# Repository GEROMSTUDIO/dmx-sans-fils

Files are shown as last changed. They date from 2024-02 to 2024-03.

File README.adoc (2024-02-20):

= DMX sans fils =

= Présentation du projet =
Le projet est de créer des boitiers DMX sans fils

= Qu'est ce que le DMX =
Le DMX est une norme dans le milieu du spectacle,
on la retrouve sur la plupart des appareils, projecteurs, machine à fumée...
 Elle permet de contrôler c'est appareil en utilisant qu'un câble.
Tout les appareils reçoivent le signal en même temps.

= Architecture =
Le projet est basée sur `Arduino`

= Fonctionnement =
Le systéme est constitué de deux boitiers, un émetteur et un récepteur.
L'émetteur lis le signal DMX envoyer par la console, l'envoie au récepteur
par onde radio (> 2.4ghz). Le récepteur écrit le signal sur le DMX.

= Composant =

* `RF-NANO`
* `MAX485`
* `WS2812D`
* `Bouton poussoir`
* `Condensateur électrolytique 16v 100µF`
* `Interupteur à glisiére`
* `Connecteur DMX (XLR)`

== License ==

 Ce travail est sous licence CC BY-NC-SA 4.0© 2024 <geromstudio@hotmail.com> (edited by GEROM STUDIO)

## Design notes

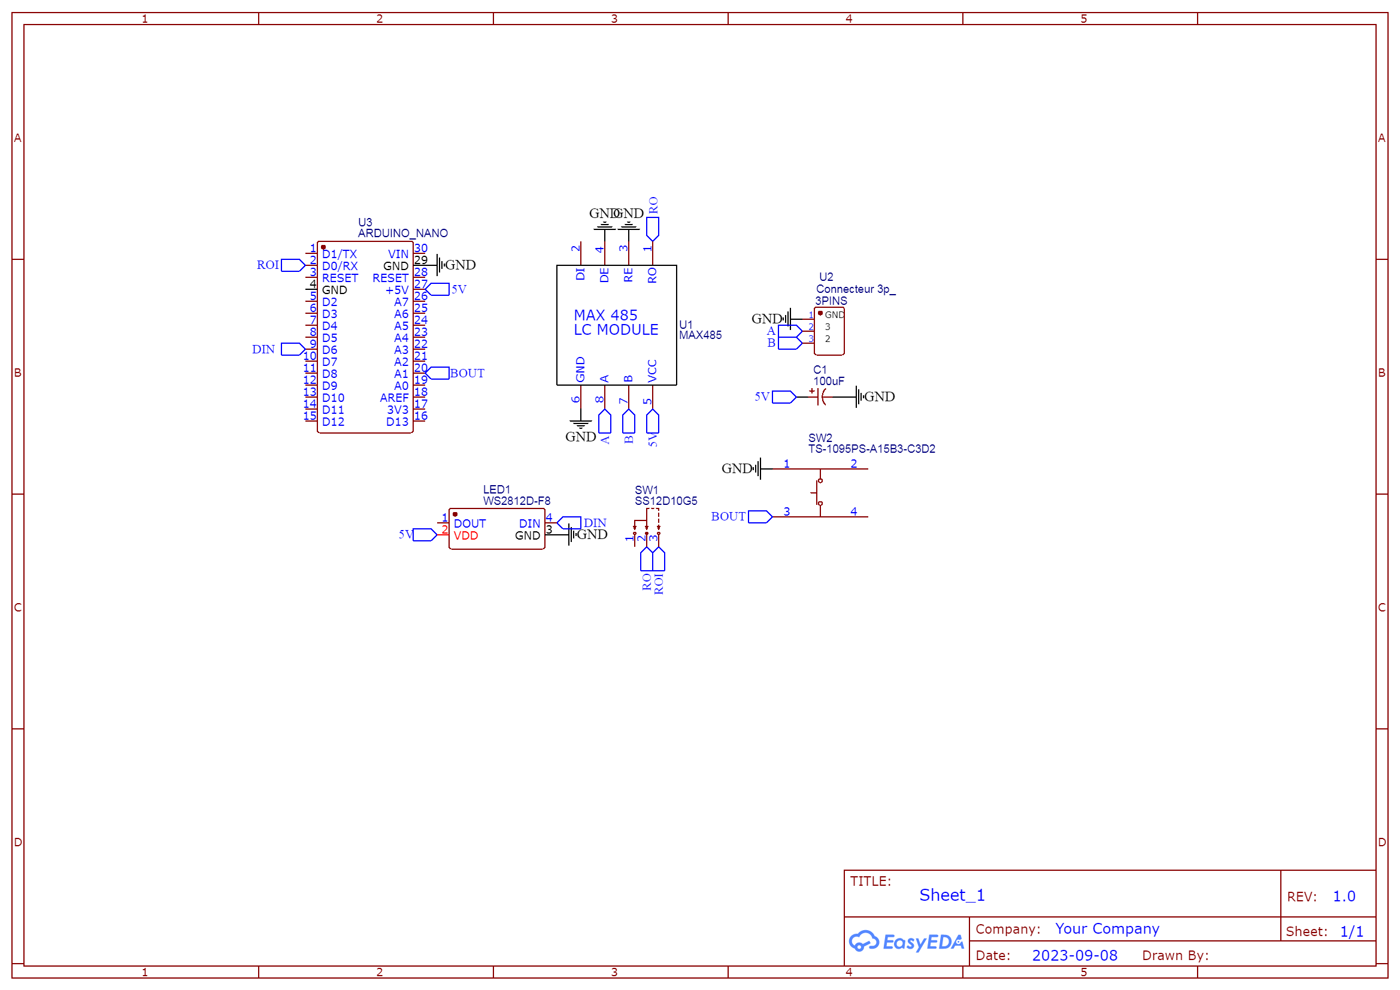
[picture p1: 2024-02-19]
Shéma/Schematic_DMX-sans-fils-émetteur-V.4.0.png

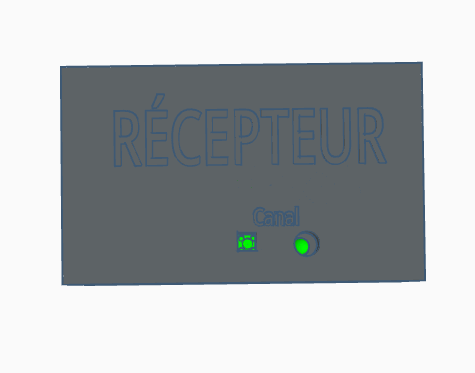
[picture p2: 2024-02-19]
Boitiers 3D/Image/Capture 2.PNG

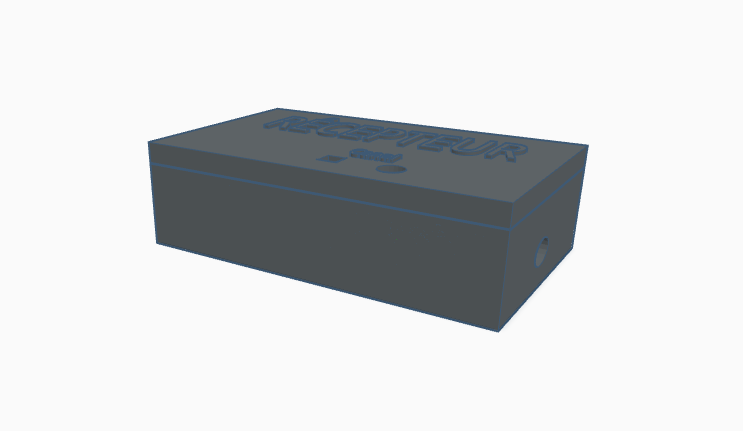
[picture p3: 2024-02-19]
Boitiers 3D/Image/Capture.PNG

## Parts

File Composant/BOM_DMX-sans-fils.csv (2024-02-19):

ID | Name | Designator | Footprint | Quantity | Manufacturer Part | Manufacturer | Supplier | Supplier Part | Price | link
1 | 100uF | C1 | CAP-TH_BD5.0-P2.00-D0.5-FD-1 | 1 | 01EC1385 | KNSCHA(???) | LCSC | C2831771 | 0.013
2 | WS2812D-F8 | LED1 | LED-TH_WS2812D-F8 | 1 | WS2812D-F8 | worldsemi | LCSC | C139126 | 0.183
3 | SS12D10G5 | SW1 | SW-TH_SHOU-HAN_SS12D10G4 | 1 | SS12D10G5 | SHOU HAN(??) | LCSC | C7431054 | 0.145
4 | TS-1095PS-A15B3-C3D2 | SW2 | KEY-SMD_4P-L6.0-W6.0-P3.90-LS9.0 | 1 | TS-1095PS-A15B3-C3D2 | Yuandi(??) | LCSC | C2834957 | 0.06

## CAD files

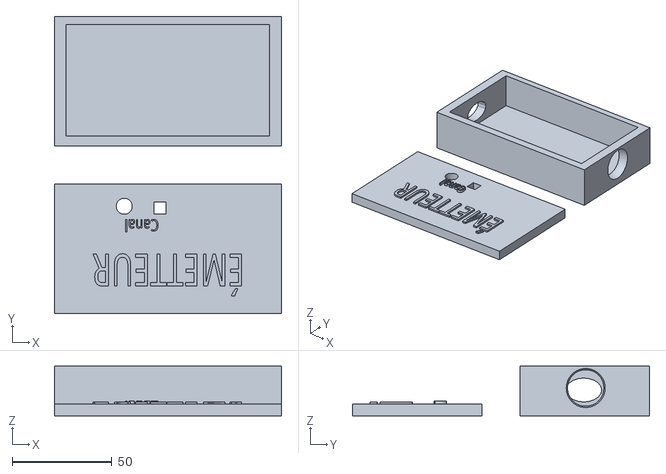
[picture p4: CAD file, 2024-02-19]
Boitiers 3D/Fichiers/Boitier émetteur.stl
114.1 x 149.0 x 25.0

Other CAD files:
Boitiers 3D/Fichiers/Boitier récepteur.stl

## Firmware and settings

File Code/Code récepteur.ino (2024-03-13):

#include <EEPROM.h>
#include <SPI.h>
#include <RF24.h>
#include <FastLED.h>
#include <DmxSimple.h>

#define NUM_LEDS 1 // Nombre de LEDs dans la bande
#define DATA_PIN 6  // Broche de données à laquelle la led est connectée

CRGB leds[NUM_LEDS]; // Déclaration d'un tableau de LED

#define pinCE   10             // Broche CE du NRF24L01
#define pinCSN  9              // Broche CSN du NRF24L01
#define tunnel  "PIPE1"        // Nom du tunnel de communication

RF24 radio(pinCE, pinCSN);     // Instanciation du NRF24L01

const byte adresse[6] = tunnel;       // Adresse du tunnel
char message[32];                     // Données reçues
int buttonPin = A1;                   // Broche du bouton
int channelIndex = 0;                 // Index du canal courant
int channelMap[] = {1, 4, 7, 10, 13, 16, 19, 22}; // Canaux disponibles
unsigned long timeout = 5000;         // Délai d'attente pour trouver un canal disponible en millisecondes
bool searching = false;               // Indique si la recherche est en cours
bool boutonEtatPrecedent = HIGH; // État précédent du bouton
unsigned long tempsDebutAppui = 0; // Temps au début de l'appui
int mode = 1;
byte valeursRecues[32]; // Pour recevoir les données
unsigned long lastReceiveTime = 0; // Temps de la dernière réception

void setup() {
  Serial.begin(9600);
  DmxSimple.usePin(3);
  DmxSimple.maxChannel(186); // Configuration pour un maximum de 186 canaux
  pinMode(buttonPin, INPUT_PULLUP);
  FastLED.addLeds<WS2812B, DATA_PIN, RGB>(leds, NUM_LEDS);
  radio.begin();
  radio.openReadingPipe(0, adresse);
  loadModeFromEEPROM(); // Ajout pour charger le mode depuis l'EEPROM au démarrage
  //radio.setPALevel(RF24_PA_MIN);
  setModeConfiguration();
  radio.setChannel(channelMap[mode - 1]); // Changer le canal RF en fonction du mode
  radio.startListening(); // Commencer l'écoute initialement
}

void loop() {
  unsigned long currentMillis = millis();
  bool boutonEtat = digitalRead(buttonPin);

if (radio.available()) {
    setModeConfiguration();
    Serial.println("Données reçues !!");
    memset(valeursRecues, 0, sizeof(valeursRecues)); // Réinitialisation du buffer
    radio.read(&valeursRecues, sizeof(valeursRecues));
    lastReceiveTime = currentMillis; // Mettre à jour le temps de la dernière réception
    
    byte indicateur = valeursRecues[0];

    // Logique adaptée pour utiliser DmxSimple selon l'indicateur
    for (int b = 1; b <= 31; b++) {
      int channelOffset = (indicateur - 1) * 31;
      DmxSimple.write(b + channelOffset, valeursRecues[b]);
    }
  }
  
  // Incrémenter le mode si le bouton est enfoncé
  if (boutonEtat == LOW && boutonEtatPrecedent == HIGH) { // Correction du nom de la variable
    delay(150); // Debouncing
    if (digitalRead(buttonPin) == LOW) { // Vérification après debounce
      mode++;
      if (mode > 8) { mode = 1; }
      saveModeToEEPROM();
      setModeConfiguration();
      radio.stopListening(); // Arrêter l'écoute
      radio.setChannel(channelMap[mode - 1]); // Changer le canal RF en fonction du mode
      radio.startListening(); // Reprendre l'écoute
    }
  }

  // Vérification si le bouton est enfoncé depuis plus de 10 secondes
  if (boutonEtat == LOW && boutonEtatPrecedent == HIGH) {
    tempsDebutAppui = millis(); // Enregistrer le moment où le bouton est enfoncé
  }
  if (boutonEtat == HIGH && boutonEtatPrecedent == LOW && (currentMillis - tempsDebutAppui) >= 10000) {
    searchChannel(); // Activer la fonction searchChannel si le bouton est relâché après avoir été enfoncé pendant plus de 10 secondes
  }

  // Mise à jour de l'état précédent du bouton
  boutonEtatPrecedent = boutonEtat;

  // Si la recherche est en cours et que le délai d'attente est écoulé, arrêter la recherche
  if (searching && currentMillis - timeout >= timeout) {
    searching = false;
    Serial.println("Aucun canal disponible trouvé. Arrêt de la recherche.");
    setModeConfiguration();
  }
   
   // Vérification si aucun signal n'a été reçu depuis plus de 5000 millisecondes
  if (currentMillis - lastReceiveTime >= 3000) {
    // Clignoter la LED dans la couleur du mode actuel
    blinkLED();
  }
}

// Fonction pour la recherche de canal disponible
void searchChannel() {
  Serial.println("Début de la recherche de canal disponible...");
  searching = true;
  for (int i = 0; i < sizeof(channelMap) / sizeof(channelMap[0]); i++) { // Correction du nom du tableau
    blinkLEDDuringSearch();
    radio.stopListening(); // Arrêter l'écoute
    radio.setChannel(channelMap[i]); // Changer de canal
    radio.startListening(); // Reprendre l'écoute
    unsigned long startMillis = millis();
    
    while (millis() - startMillis < timeout) {
      if (radio.available()) {
        Serial.print("Canal RF trouvé : ");
        Serial.println(channelMap[i]);
        mode = i + 1;
        setModeConfiguration();
        saveModeToEEPROM();
        searching = false;
        return; // Sortir de la fonction après avoir trouvé un canal
      }
    }
  }
}

// Fonction pour faire clignoter la LED pendant la recherche de canal
void blinkLEDDuringSearch() {
  static unsigned long previousMillis = 0;
  static bool ledState = false;

  unsigned long currentMillis = millis();

  if (currentMillis - previousMillis >= 200) { // Clignotement toutes les 200 millisecondes
    previousMillis = currentMillis;
    if (ledState) {
      leds[0] = CRGB::Black; // Éteindre la LED
    } else {
      // Utiliser la couleur du mode actuel pour le clignotement
      if (mode == 1) {
        leds[0] = CRGB::Red;
      } else if (mode == 2) {
        leds[0] = CRGB::Green;
      } else if (mode == 3) {
        leds[0] = CRGB::Blue;
      } else if (mode == 4) {
        leds[0] = CRGB::Yellow;
      } else if (mode == 5) {
        leds[0] = CRGB::Purple;
      } else if (mode == 6) {
        leds[0] = CRGB::Cyan;
      } else if (mode == 7) {
        leds[0] = CRGB::White;
      } else if (mode == 8) {
        leds[0] = CRGB::OrangeRed; // Utiliser une nuance plus rouge pour le mode 8
      }
    }
    FastLED.show();
    ledState = !ledState;
  }
}

// Fonction pour faire clignoter la LED avec la couleur du mode actuel
void blinkLED() {
  static unsigned long previousMillis = 0;
  static bool ledState = false;

  unsigned long currentMillis = millis();

  if (currentMillis - previousMillis >= 500) { // Clignotement toutes les 500 millisecondes
    previousMillis = currentMillis;
    if (ledState) {
      leds[0] = CRGB::Black; // Éteindre la LED
    } else {
      // Utiliser la couleur du mode actuel pour le clignotement
      if (mode == 1) {
        leds[0] = CRGB::Red;
      } else if (mode == 2) {
        leds[0] = CRGB::Green;
      } else if (mode == 3) {
        leds[0] = CRGB::Blue;
      } else if (mode == 4) {
        leds[0] = CRGB::Yellow;
      } else if (mode == 5) {
        leds[0] = CRGB::Purple;
      } else if (mode == 6) {
        leds[0] = CRGB::Cyan;
      } else if (mode == 7) {
        leds[0] = CRGB::White;
      } else if (mode == 8) {
        leds[0] = CRGB::OrangeRed; // Utiliser une nuance plus rouge pour le mode 8
      }
    }
    FastLED.show();
    ledState = !ledState;
  }
}

void setModeConfiguration() {
  // Configuration du mode et de la couleur des LEDs selon le mode
  if (mode == 1) {
    leds[0] = CRGB::Red;
  } else if (mode == 2) {
    leds[0] = CRGB::Green;
  } else if (mode == 3) {
    leds[0] = CRGB::Blue;
  } else if (mode == 4) {
    leds[0] = CRGB::Yellow;
  } else if (mode == 5) {
    leds[0] = CRGB::Purple;
  } else if (mode == 6) {
    leds[0] = CRGB::Cyan;
  } else if (mode == 7) {
    leds[0] = CRGB::White;
  } else if (mode == 8) {
    leds[0] = CRGB::OrangeRed; // Utiliser une nuance plus rouge pour le mode 8
  }
  FastLED.show();
}

void saveModeToEEPROM() {
  EEPROM.write(0, mode);
}

void loadModeFromEEPROM() {
  mode = EEPROM.read(0);
}

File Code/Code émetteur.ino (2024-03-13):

#include <EEPROM.h>
#include <SPI.h>
#include <RF24.h>
#include <DMXSerial.h>
#include <FastLED.h>

#define NUM_LEDS 1 // Nombre de LEDs dans la bande
#define DATA_PIN 6  // Broche de données à laquelle la LED est connectée

CRGB leds[NUM_LEDS]; // Déclaration d'un tableau de LED

#define pinCE   10
#define pinCSN  9
#define tunnel  "PIPE1"        // Nom du tunnel de communication

RF24 radio(pinCE, pinCSN);
const byte adresse[6] = tunnel;                // Adresse du tunnel
byte valeursEnvoyees1[32]; // Canaux 1-31
byte valeursEnvoyees2[32]; // Canaux 32-62
byte valeursEnvoyees3[32]; // Canaux 63-93
byte valeursEnvoyees4[32]; // Canaux 94-124
byte valeursEnvoyees5[32]; // Canaux 125-155
byte valeursEnvoyees6[32]; // Canaux 156-186
const int boutonPin = A1;
int mode = 1;
uint8_t channelMap[8] = {1, 4, 7, 10, 13, 16, 19, 22}; // Écart de 3 entre chaque canal

void setup() {
  DMXSerial.init(DMXReceiver);
  pinMode(boutonPin, INPUT_PULLUP);
  FastLED.addLeds<WS2812B, DATA_PIN, RGB>(leds, NUM_LEDS);
  radio.begin();
  radio.openWritingPipe(adresse); // Ouvrir un canal d'écriture
  loadModeFromEEPROM(); // Ajout pour charger le mode depuis l'EEPROM au démarrage
  setModeConfiguration();
  radio.setChannel(channelMap[mode - 1]); // Définir le canal initial
}

void loop() {
  
  // Lire l'état du bouton
  int etatBouton = digitalRead(boutonPin);

  // Incrémenter le mode si le bouton est enfoncé
  if (etatBouton == LOW) {
    delay(150); // Débouncing
    if (etatBouton == LOW) { // Vérifier de nouveau pour éviter les faux déclenchements
      mode++;
      if (mode > 8) {
        mode = 1;
      }
      setModeConfiguration();
      saveModeToEEPROM(); // Sauvegarder le mode dans l'EEPROM
      radio.setChannel(channelMap[mode - 1]); // Changer le canal RF en fonction du mode
    }
  }

    // Vérifier si aucun signal DMX n'a été reçu depuis plus de 3000 ms
  if (DMXSerial.noDataSince() > 3000) {
    // Clignoter la LED dans la couleur du mode actuel
    blinkLED();
   } else {
   setModeConfiguration();
  // Sinon, continuer à recevoir et à envoyer des données DMX
  memset(valeursEnvoyees1, 0, sizeof(valeursEnvoyees1));
  memset(valeursEnvoyees2, 0, sizeof(valeursEnvoyees2));
  memset(valeursEnvoyees3, 0, sizeof(valeursEnvoyees3));
  memset(valeursEnvoyees4, 0, sizeof(valeursEnvoyees4));
  memset(valeursEnvoyees5, 0, sizeof(valeursEnvoyees5));
  memset(valeursEnvoyees6, 0, sizeof(valeursEnvoyees6));
  
  valeursEnvoyees1[0] = 1; // Indicateur pour les canaux 1-31
  valeursEnvoyees2[0] = 2; // Indicateur pour les canaux 32-62
  valeursEnvoyees3[0] = 3; // Indicateur pour les canaux 63-93
  valeursEnvoyees4[0] = 4; // Indicateur pour les canaux 94-124
  valeursEnvoyees5[0] = 5; // Indicateur pour les canaux 125-155
  valeursEnvoyees6[0] = 6; // Indicateur pour les canaux 156-186

  for (int i = 1; i <= 31; i++) {
    valeursEnvoyees1[i] = DMXSerial.read(i);
    valeursEnvoyees2[i] = DMXSerial.read(i + 31);
    valeursEnvoyees3[i] = DMXSerial.read(i + 62);
    valeursEnvoyees4[i] = DMXSerial.read(i + 93);
    valeursEnvoyees5[i] = DMXSerial.read(i + 124);
    valeursEnvoyees6[i] = DMXSerial.read(i + 155);
  }
   }

  radio.write(&valeursEnvoyees1, sizeof(valeursEnvoyees1));
  delay(1); // Un petit délai pour éviter l'interférence
  radio.write(&valeursEnvoyees2, sizeof(valeursEnvoyees2));
  delay(1);
  radio.write(&valeursEnvoyees3, sizeof(valeursEnvoyees3));
   delay(1);
  radio.write(&valeursEnvoyees4, sizeof(valeursEnvoyees4));
  delay(1);
  radio.write(&valeursEnvoyees5, sizeof(valeursEnvoyees5));
  delay(1);
  radio.write(&valeursEnvoyees6, sizeof(valeursEnvoyees6));
}

// Fonction pour faire clignoter la LED avec la couleur du mode actuel
void blinkLED() {
  static unsigned long previousMillis = 0;
  static bool ledState = false;

  unsigned long currentMillis = millis();

  if (currentMillis - previousMillis >= 500) { // Clignotement toutes les 500 millisecondes
    previousMillis = currentMillis;
    if (ledState) {
      leds[0] = CRGB::Black; // Éteindre la LED
    } else {
      // Utiliser la couleur du mode actuel pour le clignotement
      if (mode == 1) {
        leds[0] = CRGB::Red;
      } else if (mode == 2) {
        leds[0] = CRGB::Green;
      } else if (mode == 3) {
        leds[0] = CRGB::Blue;
      } else if (mode == 4) {
        leds[0] = CRGB::Yellow;
      } else if (mode == 5) {
        leds[0] = CRGB::Purple;
      } else if (mode == 6) {
        leds[0] = CRGB::Cyan;
      } else if (mode == 7) {
        leds[0] = CRGB::White;
      } else if (mode == 8) {
        leds[0] = CRGB::OrangeRed; // Utiliser une nuance plus rouge pour le mode 8
      }
    }
    FastLED.show();
    ledState = !ledState;
  }
}

void setModeConfiguration() {
  // Configuration du mode et de la couleur des LEDs selon le mode
  if (mode == 1) {
    leds[0] = CRGB::Red;
  } else if (mode == 2) {
    leds[0] = CRGB::Green;
  } else if (mode == 3) {
    leds[0] = CRGB::Blue;
  } else if (mode == 4) {
    leds[0] = CRGB::Yellow;
  } else if (mode == 5) {
    leds[0] = CRGB::Purple;
  } else if (mode == 6) {
    leds[0] = CRGB::Cyan;
  } else if (mode == 7) {
    leds[0] = CRGB::White;
  } else if (mode == 8) {
    leds[0] = CRGB::OrangeRed; // Utiliser une nuance plus rouge pour le mode 8
  }
  FastLED.show();
}

void saveModeToEEPROM() {
  EEPROM.write(0, mode); // Enregistrer le mode dans l'EEPROM à l'adresse 0
}

void loadModeFromEEPROM() {
  mode = EEPROM.read(0); // Charger le mode depuis l'EEPROM à l'adresse 0
}

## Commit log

2024-02-19 Circuits imprimés
2024-02-19 Boitiers 3D
    [Boitier récepteur.stl, Boitier émetteur.stl]
2024-02-19 Lien composants
    [BOM_DMX-sans-fils.csv]
